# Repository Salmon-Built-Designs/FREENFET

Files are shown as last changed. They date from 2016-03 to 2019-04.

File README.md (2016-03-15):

Freetronics FreeNFET Addressable N-MOSFET Module
================================================
Copyright 2016 Freetronics Pty Ltd  
Freetronics site:  www.freetronics.com  
Freetronics email: info@freetronics.com  

This is a FET with a brain! Includes an NTD5867NL N-channel MOSFET and
a WS2811 addressable LED driver. That means you can connect the module
and address it just as if it was a NeoPixel or other WS28xx RGB LED, 
except that instead of controlling an LED, you're controlling a high-power
MOSFET.

This smart module can be daisy-chained, so you can connect a number of
these together in a string and drive each of them individually from your
microcontroller.

Compatible with various Arduino libraries for the WS2811, including
the FastLED library and the NeoPixel library. Simply control the "red"
channel to control the FET.

Features:

 * Switch up to 60V / 18A DC.
 * Requires just 1 data connection.
 * PWM control of the FET.
 * Input and output headers on opposite sides of the board for easy
   daisy-chaining.

More information is available at:

  http://www.freetronics.com.au/freenfet

INSTALLATION
------------
The design is saved as an EAGLE project. EAGLE PCB design software is
available from www.cadsoftusa.com free for non-commercial use. To use
this project download it and place the directory containing these files
into the "eagle" directory on your computer.

DISTRIBUTION
------------
The specific terms of distribution of this project are governed by the
license referenced below.

LICENSE
-------
Licensed under the TAPR Open Hardware License (www.tapr.org/OHL).
The "license" folder within this repository also contains a copy of
this license in plain text format.

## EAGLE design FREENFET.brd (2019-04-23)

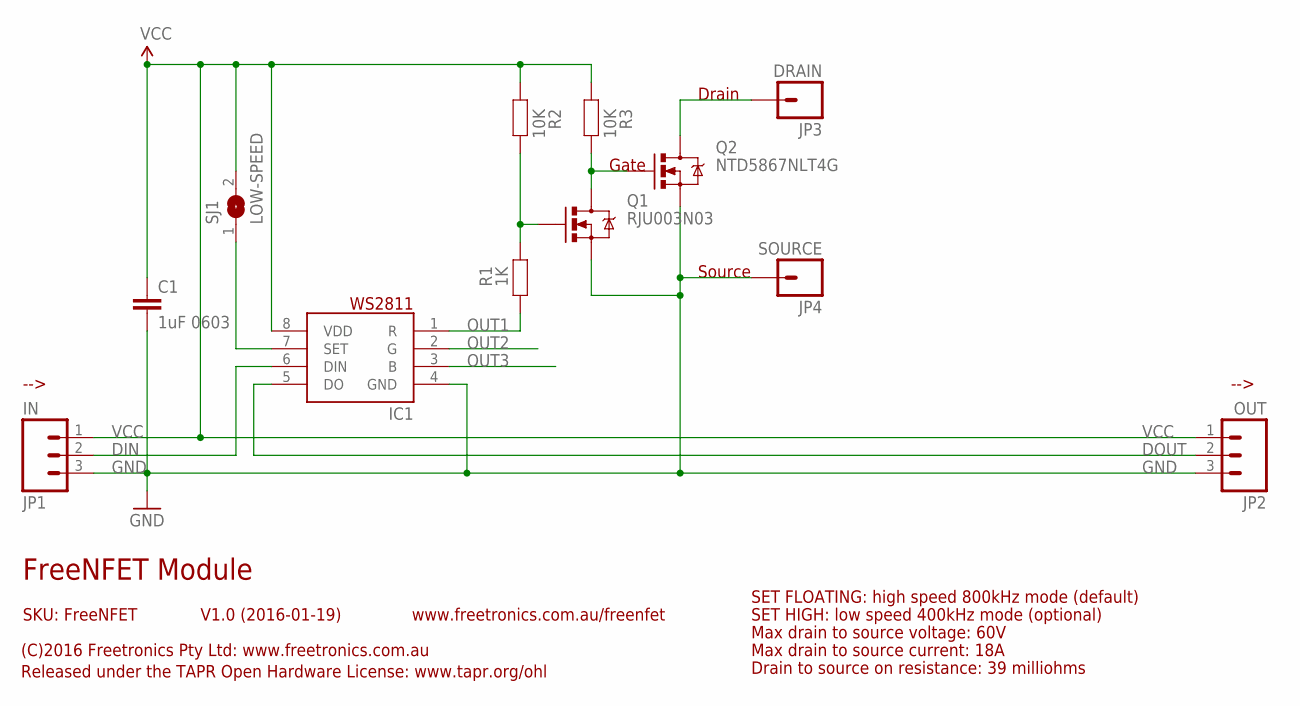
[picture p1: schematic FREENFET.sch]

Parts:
C1: 1uF 0603; 0603
IC1: WS2811-SOP8; SO08-SKINNYPADS
JP1: IN; 1X03
JP2: OUT; 1X03
JP3: DRAIN; 1X01LARGE
JP4: SOURCE; 1X01LARGE
Q1: RJU003N03; SOT32-3
Q2: NTD5867NLT4G; DPACK
R1: 1K; 0603
R2, R3: 10K; 0603
SJ1: LOW-SPEED; SJ

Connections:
D: JP3.1, Q2.2 (D)
DIN: IC1.6 (DIN), JP1.2
DOUT: IC1.5 (DO), JP2.2
GND: C1.2, IC1.4 (GND), JP1.3, JP2.3, JP4.1, Q1.2 (S), Q2.3 (S)
unnamed: IC1.7 (SET), SJ1.1
unnamed: Q1.1 (G), R1.1, R2.1
unnamed: Q1.3 (D), Q2.1 (G), R3.1
OUT1: IC1.1 (R), R1.2
OUT2: IC1.2 (G)
OUT3: IC1.3 (B)
VCC: C1.1, IC1.8 (VDD), JP1.1, JP2.1, R2.2, R3.2, SJ1.2

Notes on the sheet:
FreeNFET Module
V1.0 (2016-01-19)
SKU: FreeNFET
(C)2016 Freetronics Pty Ltd: www.freetronics.com.au
Released under the TAPR Open Hardware License: www.tapr.org/ohl
www.freetronics.com.au/freenfet
-->
SET HIGH: low speed 400kHz mode (optional)
Max drain to source current: 18A
Drain
Gate
Source
Max drain to source voltage: 60V
Drain to source on resistance: 39 milliohms
SET FLOATING: high speed 800kHz mode (default)

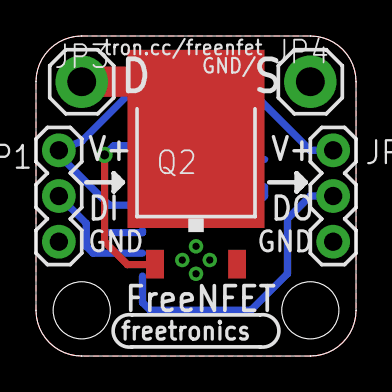
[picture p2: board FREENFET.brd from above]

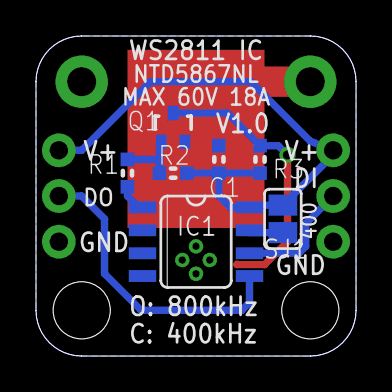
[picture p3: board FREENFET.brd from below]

Board: 2 copper layers, 17.8 x 17.8 mm, 12 parts (7 on the bottom side), 9 nets.

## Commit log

2016-03-15 Initial import of project for v1.0 release
    [FREENFET.brd, FREENFET.sch]
2016-03-30 Clarified schematic and silkscreen
    [FREENFET.brd, FREENFET.sch]
2019-04-23 Designator improvement
    [FREENFET.brd, FREENFET.sch]
